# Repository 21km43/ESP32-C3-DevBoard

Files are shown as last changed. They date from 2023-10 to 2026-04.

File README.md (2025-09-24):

# ESP32-C3-DevBoard
ESP32-C3 Development Board. Made with [KiCAD 9.0](https://KiCAD.org)

You can get ESP32-C3-WROOM-02 from here.  
* [秋月電子](https://akizukidenshi.com/catalog/g/gM-17493/)  
* [DigiKey](https://www.digikey.jp/ja/products/detail/espressif-systems/ESP32-C3-WROOM-02-N4/14553031)
* [Mouser](https://www.mouser.jp/ProductDetail/Espressif-Systems/ESP32-C3-WROOM-02-N4?qs=stqOd1AaK7%2FqjTZKEOgfUg%3D%3D)

Orders can be placed by uploading data(Gerber, BOM, and CPL) to the JLCPCB. 
This project uses [Espressif Library for KiCAD](https://github.com/espressif/kicad-libraries). (It is available on Plugin & Contents manager.)  
Gerber, bom and cpl is placed on [production folder](/production) directory and Release. 

## Features
* Upload method: USB (Do not use GPIO 18 and 19 when downloading)
* USB: Type-C (USB 2.0)
* Regulator: [RT9080-33GJ5](https://www.richtek.com/Products/Linear%20Regulator/Single%20Output%20Linear%20Regulator/RT9080?sc_lang=en).
* External input voltage range: 4.3-6.5V (4.5V-5.5V is recommended)
* Power consumption (in deep sleep): 11.5µA (ESP32-C3: 5µA, RT9080-33GJ5: 6.5µA)

### Solder Jumpers
* JP1 ... VBUS = 5V jumper (Default: not connected): Connecting this disables the protective SBD between USB and external power supply. To eliminate the voltage drop due to SBD and output the voltage input from USB as it is to 5V, connect this jumper. Note that shorting this pin will increase current consumption by about 0.1mA due to the pull-down resistor on the CC pin.
* JP2 ... 5V -> 3.3V jumper (Default: connected): Connection of the external power supply terminal (5V pin) to the power input terminal to the ESP32-C3. Disconnect when suppressing regulator quiescent current.

## BOM
[BOM](/production/bom.csv)

### Notice

When using Fabrication-Toolkit, Please check "Apply automatic translations" option.

## 3D image
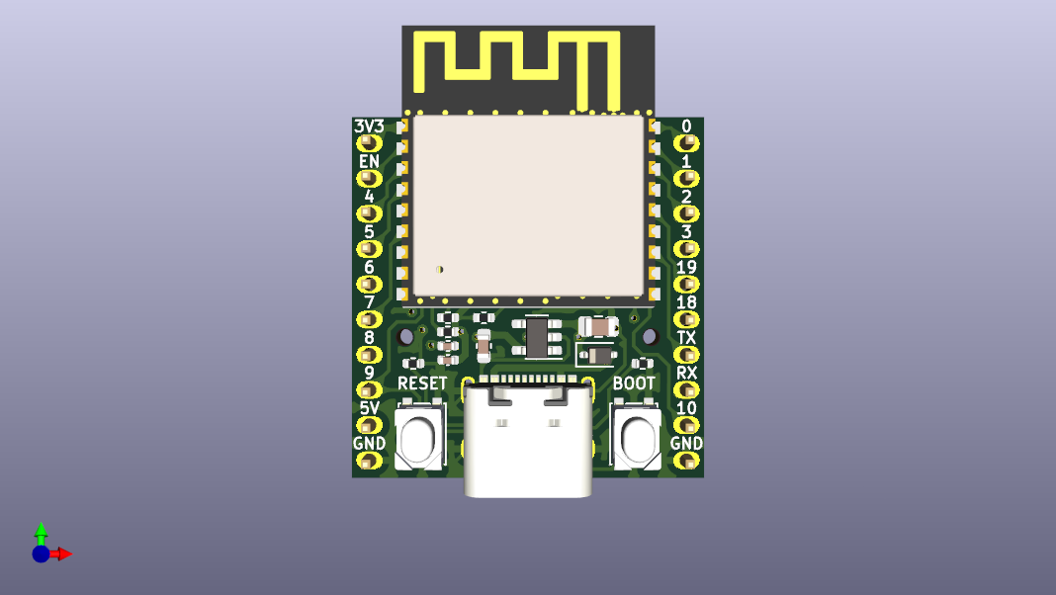
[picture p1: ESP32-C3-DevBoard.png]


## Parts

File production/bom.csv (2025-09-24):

Designator | Footprint | Quantity | Value | LCSC Part #
C1 | 0805 | 1 | 10u | C15850
C2 | 0603 | 1 | 22u | C59461
C3 | 0402 | 1 | 1u | C52923
C4 | 0402 | 1 | 100n | C1525
D1 | D_SOD-323 | 1 | 1N5819WS | C191023
J1 | USB_C_Receptacle_XKB_U262-16XN-4BVC11 | 1 | USB_C_Receptacle_USB2.0_16P | C2988369
R1, R2 | 0402 | 2 | 5.1k | C25905
R3, R4, R5 | 0402 | 3 | 10k | C25744
SW1, SW2 | SW_SPST_PTS810 | 2 | SW_Push | C115360
U1 | ESP32-C3-WROOM-02 | 1 | ESP32-C3-WROOM-02 | C2934560
U3 | SOT-23-5 | 1 | RT9080-33GJ5 | C841192

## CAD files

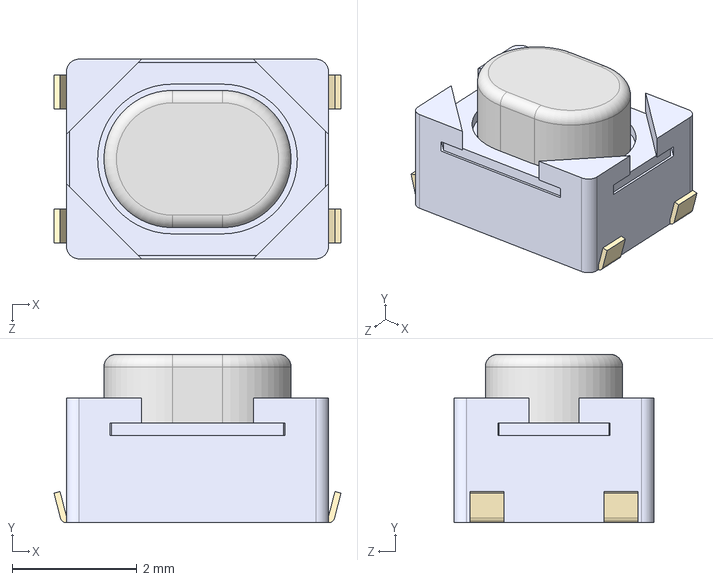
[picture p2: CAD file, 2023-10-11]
3d/PTS810.STEP
4.60 x 2.70 x 3.20 mm

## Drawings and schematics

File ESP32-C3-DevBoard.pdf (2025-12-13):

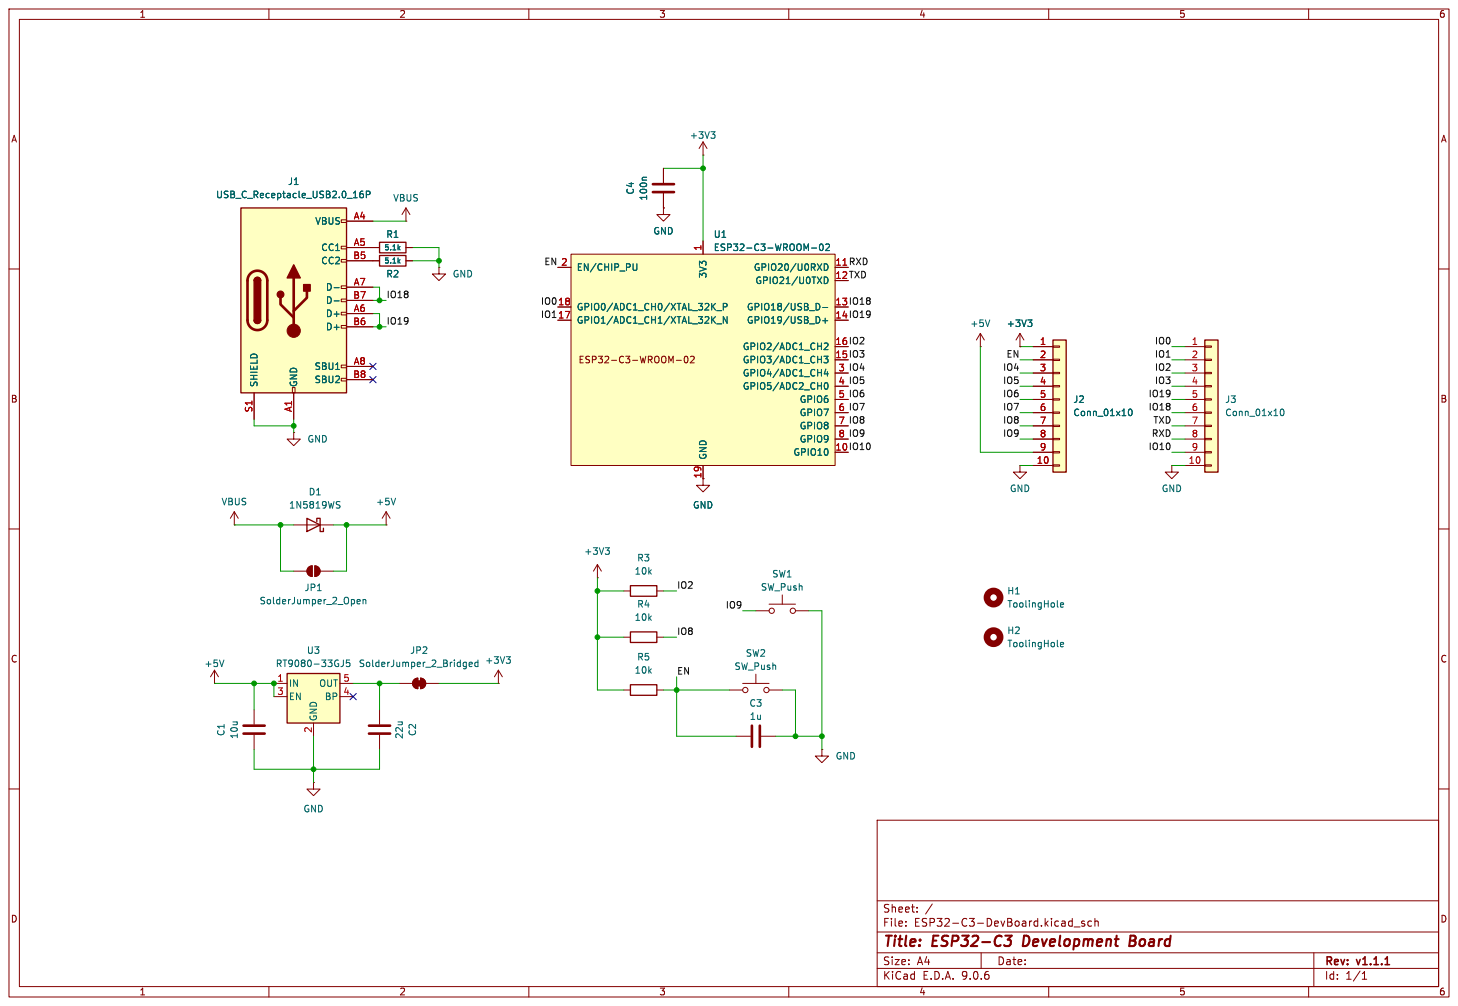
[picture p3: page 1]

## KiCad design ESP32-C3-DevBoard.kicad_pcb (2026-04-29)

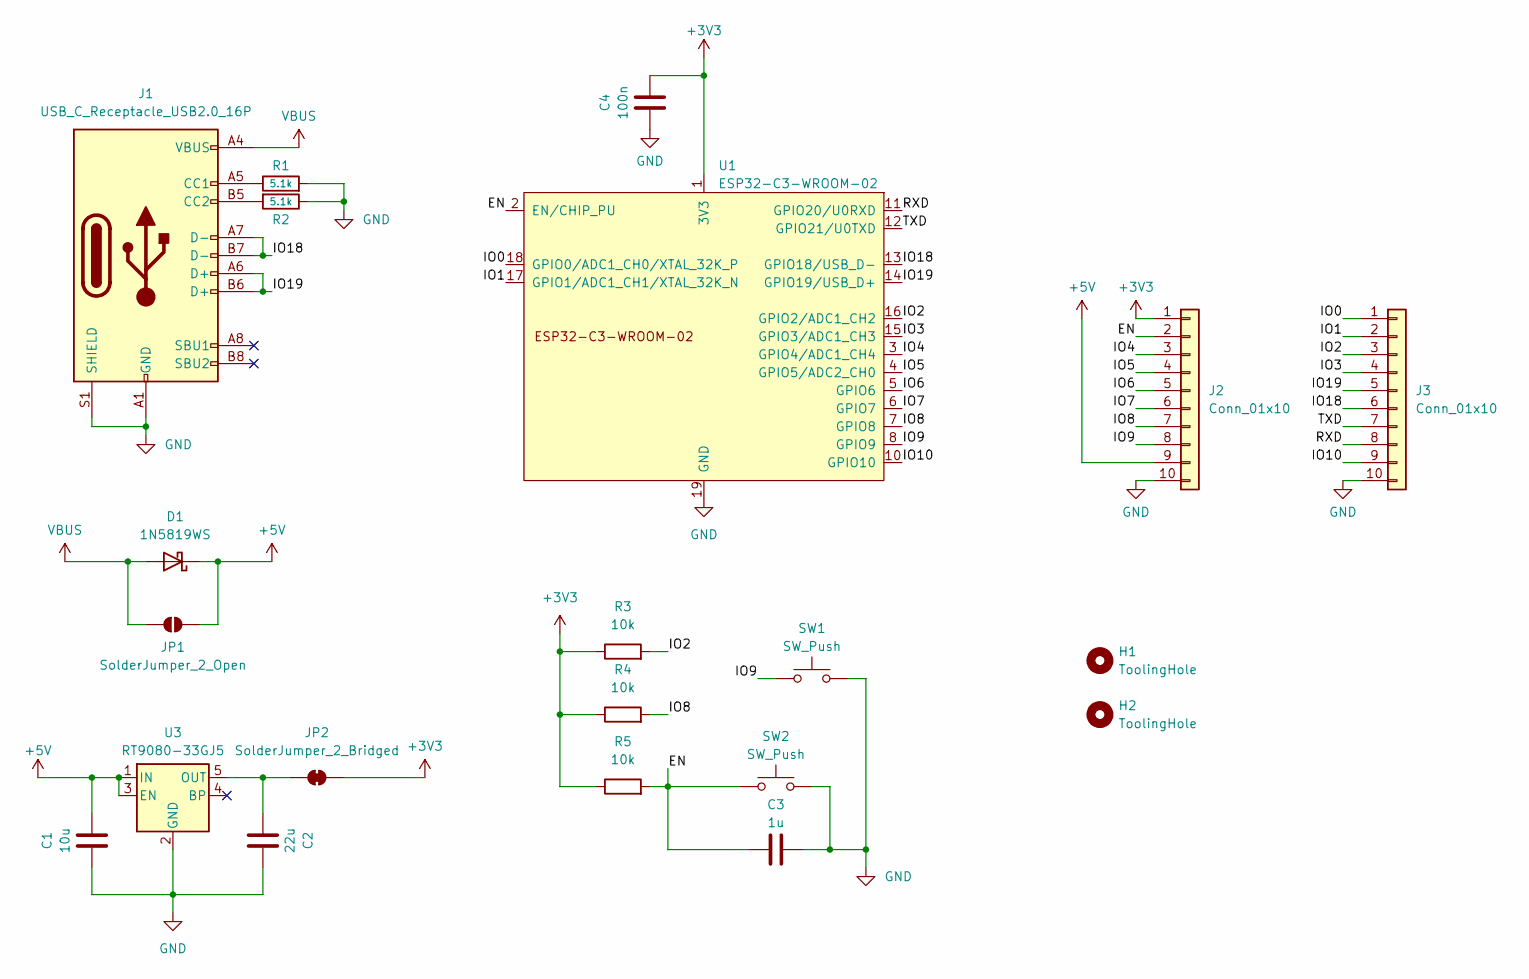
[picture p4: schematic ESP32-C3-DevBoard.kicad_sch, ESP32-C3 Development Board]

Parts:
C1: 10u; C_0805_2012Metric; LCSC Part # C15850
C2: 22u; C_0603_1608Metric; LCSC Part # C59461
C3: 1u; C_0402_1005Metric; LCSC Part # C52923
C4: 100n; C_0402_1005Metric; LCSC Part # C1525
D1: 1N5819WS; D_SOD-323; LCSC Part # C191023
H1, H2: ToolingHole; Tooling_Hole
J1: USB_C_Receptacle_USB2.0_16P; USB_C_Receptacle_XKB_U262-16XN-4BVC11; LCSC Part # C2988369
J2, J3: Conn_01x10; PinHeader_1x10_P2.54mm_Vertical
JP1: SolderJumper_2_Open; SolderJumper-2_P1.3mm_Open_RoundedPad1.0x1.5mm
JP2: SolderJumper_2_Bridged; SolderJumper-2_P1.3mm_Bridged_RoundedPad1.0x1.5mm
R1, R2: 5.1k; R_0402_1005Metric; LCSC Part # C25905
R3, R4, R5: 10k; R_0402_1005Metric; LCSC Part # C25744
SW1, SW2: SW_Push; SW_SPST_PTS810; LCSC Part # C115360
U1: ESP32-C3-WROOM-02; LCSC Part # C2934560
U3: RT9080-33GJ5; SOT-23-5; LCSC Part # C841192

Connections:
+3V3: C4.2, J2.1, JP2.2 (B), R3.1, R4.1, R5.1, U1.1 (3V3)
+5V: C1.2, D1.1 (K), J2.9, JP1.2 (B), U3.1 (IN), U3.3 (EN)
/EN: C3.1, J2.2, R5.2, SW2.1, U1.2 (EN/CHIP_PU)
/IO0: J3.1, U1.18 (GPIO0/ADC1_CH0/XTAL_32K_P)
/IO1: J3.2, U1.17 (GPIO1/ADC1_CH1/XTAL_32K_N)
/IO2: J3.3, R3.2, U1.16 (GPIO2/ADC1_CH2)
/IO3: J3.4, U1.15 (GPIO3/ADC1_CH3)
/IO4: J2.3, U1.3 (GPIO4/ADC1_CH4)
/IO5: J2.4, U1.4 (GPIO5/ADC2_CH0)
/IO6: J2.5, U1.5 (GPIO6)
/IO7: J2.6, U1.6 (GPIO7)
/IO8: J2.7, R4.2, U1.7 (GPIO8)
/IO9: J2.8, SW1.1, U1.8 (GPIO9)
/IO10: J3.9, U1.10 (GPIO10)
/IO18: J1.A7 (D-), J1.B7 (D-), J3.6, U1.13 (GPIO18/USB_D-)
/IO19: J1.A6 (D+), J1.B6 (D+), J3.5, U1.14 (GPIO19/USB_D+)
/RXD: J3.8, U1.11 (GPIO20/U0RXD)
/TXD: J3.7, U1.12 (GPIO21/U0TXD)
GND: C1.1, C2.2, C3.2, C4.1, J1.A1 (GND), J1.A12 (GND), J1.B1 (GND), J1.B12 (GND), J1.S1 (SHIELD), J2.10, J3.10, R1.2, R2.1, SW1.2, SW2.2, U1.9 (GND), U1.19 (GND), U3.2 (GND)
unnamed: J1.A5 (CC1), R1.1
unnamed: J1.B5 (CC2), R2.2
unnamed: C2.1, JP2.1 (A), U3.5 (OUT)
VBUS: D1.2 (A), J1.A4 (VBUS), J1.A9 (VBUS), J1.B4 (VBUS), J1.B9 (VBUS), JP1.1 (A)

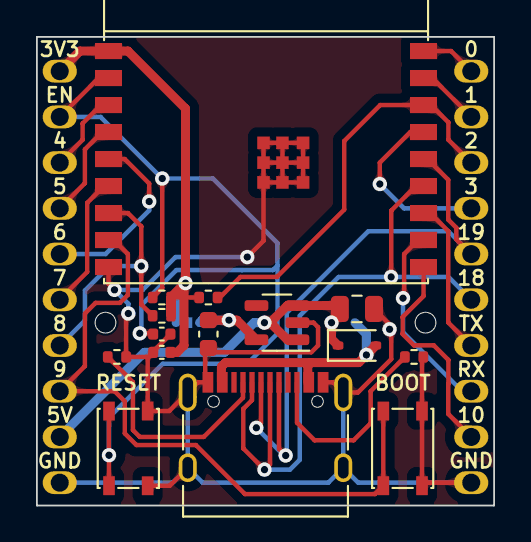
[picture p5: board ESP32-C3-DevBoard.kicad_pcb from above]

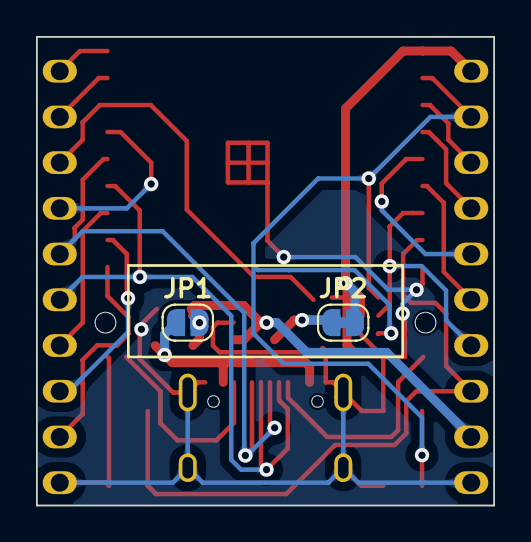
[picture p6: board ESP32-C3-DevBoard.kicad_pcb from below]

Board: 2 copper layers, 25.4 x 26.0 mm, 21 parts (4 on the bottom side), 23 nets.

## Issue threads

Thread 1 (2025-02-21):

Fabrication Toolkit plugin renamed "JLCPCB Position Offset" to "FT Position Offset" and made THT part positioning change

matej-marjanovic, 2025-02-21:
This is regarding the position of the USB-C port.

Currently, the "JLCPCB Position Offset" field is set to "0, 0.13".

Given the updates to the Fabrication Toolkit plugin (updated December 7th, 2024), I think it should now be called "FT Position Offset".
Also, I had to change the value to "0.0,1.35".

I believe this is due to the following aspects of the plugin update (https://github.com/bennymeg/Fabrication-Toolkit/releases/tag/5.0.0):
- Shorten all options name mainly by replacing JLCPCB with FT. BREAKING
- THT parts positioning by center of pads

You can see the changes in the generated positions.csv file though to really test you probably need to upload the production files to jlcpcb.com.

21km43, 2025-09-24:
Thanks for comment.
I fixed field name from "JLCPCB Position Offset" to "FT Position Offset".

In my environment, USB-C offset is fit on "0, 0.13" (Checked on KiCAD 9.0.4)...
It may depend on library version.

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

Closed 2025-09-25.

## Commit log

2023-10-11 add 3d model
    [ESP32-C3-DevBoard.kicad_pcb, ESP32-C3-DevBoard.kicad_sch, PTS810.STEP]
2023-10-13 fix tooling hole position
    [ESP32-C3-DevBoard.kicad_pcb, ESP32-C3-DevBoard.kicad_sch, bom.csv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]
2023-10-13 little fix
    [ESP32-C3-DevBoard.kicad_pcb]
2023-10-15 fix silkscreen and tooling hole position
    [ESP32-C3-DevBoard.kicad_pcb]
2023-11-19 Add Tooling Hole Library
    [ESP32-C3-DevBoard.kicad_pcb, ESP32-C3-DevBoard.kicad_sch]
2024-03-19 KiCAD 8.0
    [ESP32-C3-DevBoard.kicad_pcb, ESP32-C3-DevBoard.kicad_sch, bom.csv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]
2024-05-24 change clearance
    [ESP32-C3-DevBoard.kicad_pcb, ESP32-C3-DevBoard.kicad_sch]
2024-05-27 solder jumper fix
    [ESP32-C3-DevBoard.kicad_pcb, ESP32-C3-DevBoard.kicad_sch]
2024-06-03 gitignoreと画像を更新
2024-06-07 show reference number
    [ESP32-C3-DevBoard.kicad_pcb]
2024-06-07 jlcpcb offset fix
    [ESP32-C3-DevBoard.kicad_pcb, ESP32-C3-DevBoard.kicad_sch]
2024-06-07 mask fix
    [ESP32-C3-DevBoard.kicad_pcb]
2024-06-08 change usb component
    [ESP32-C3-DevBoard.kicad_pcb, ESP32-C3-DevBoard.kicad_sch, bom.csv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]
2024-06-09 avoid via on pad
    [ESP32-C3-DevBoard.kicad_pcb, bom.csv, designators.csv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]
2025-12-13 fix RT9080-33GJ5 description
    [ESP32-C3-DevBoard.kicad_pcb, ESP32-C3-DevBoard.kicad_sch]
2025-12-13 fix schematic
    [ESP32-C3-DevBoard.kicad_sch]
2026-04-29 fix property name
    [ESP32-C3-DevBoard.kicad_pcb, ESP32-C3-DevBoard.kicad_sch]
